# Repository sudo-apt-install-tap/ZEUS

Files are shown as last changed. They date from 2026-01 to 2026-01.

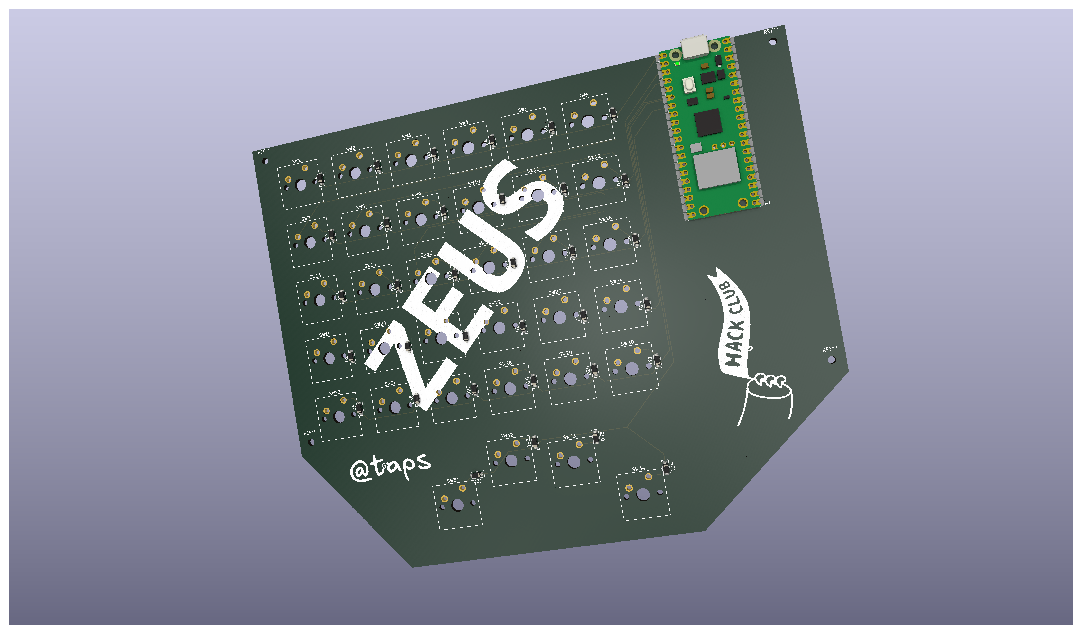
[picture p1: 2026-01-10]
Images/pcb.png

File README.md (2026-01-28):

# ZEUS: A One Handed Keeb Made For Speed
**No extra keys. Only essentials. Built for speed, precision, and one-handed precession.**

## Why ZEUS?
Zeus has a custom layout designed for speed and efficiency. This is based on a generic one handed gaming board.. yeah the kind you get on alibaba. BUT!! the diffrence is instead of keys numeric or function keys it has all alphabet keys. This make it perfect for speed typists.

## How Do I Flash ZEUS?
WHY WOULD YOU WANNA FLASH A GOD WHO HAS A HISTORY OF ADULTRY AND CREATING DEMIGODS. /j
But in all seriousness you just need to get the firmware and then just flash the code through any ide.

## RENDER
pcb


## PCB
PCB Layout
Matrix Routing
PCB Routing 1
PCB Routing 2

## Schematic
PCB Schematic

## BOM
### *not a bomb a BOM, Bill Of Materials*

| ID | Component | Qty | Designation | Supplier | Unit (INR) | Total (INR) |
|----|---|-----|---|---|---|---|
| 1 | Diode SMD 123 | 36 | 1N4148WT | [Robu](https://robu.in/product/tpmbr140sft1g-tech-public-sod-123-schottky-diodes-rohs/) | ₹2.49 | ₹89.64 |
| 2 | Switches (Pack of 10) | 4 | SW_Push | [StacksKB](https://stackskb.com/store/click-inc-hp-switch-pack-of-10-pre-order/) | ₹180.00 | ₹720.00 |
| 3 | Raspberry Pi Pico W | 1 | RaspberryPi_Pico_W | [Robu](https://robu.in/product/raspberry-pi-pico-w/) | ₹614.00 | ₹614.00 |
| 4 | Keycaps | 1 | — | [StacksKB](https://stackskb.com/store/veekos-gradient-keycaps-cherry-profile-135-keys/) | ₹1,299.00 | ₹1,299.00 |
| 5 | Hotswap Sockets | 34 | SW_Push | [StacksKB](https://stackskb.com/store/ttc-pokayoke-hotswap-sockets-v2-10000-cycles) | ₹10.00 | ₹340.00 |
| 6 | PCB Fabrication | 1 | — | [JLCPCB](https://cart.jlcpcb.com/shopcart/cart) | ₹2,294.11 | ₹2,294.11 |

---

### 💸 Cost Summary

- **Total (INR): ₹5,356.75**
- **Total (USD): ~$59.34**
- **Additional Cost [Case + Plate] (USD): $40**
- **Rounded:** **$100**

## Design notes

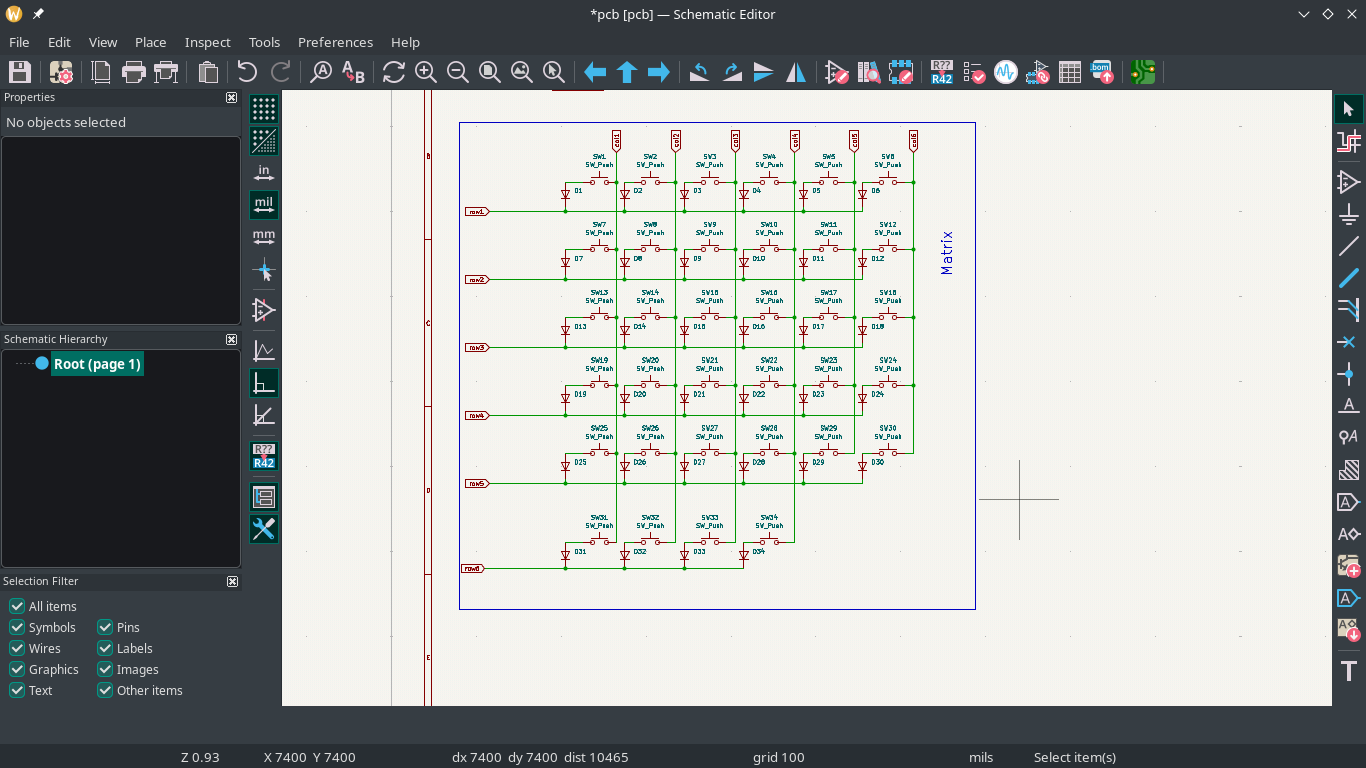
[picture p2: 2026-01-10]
Images/PCB Schematic.png

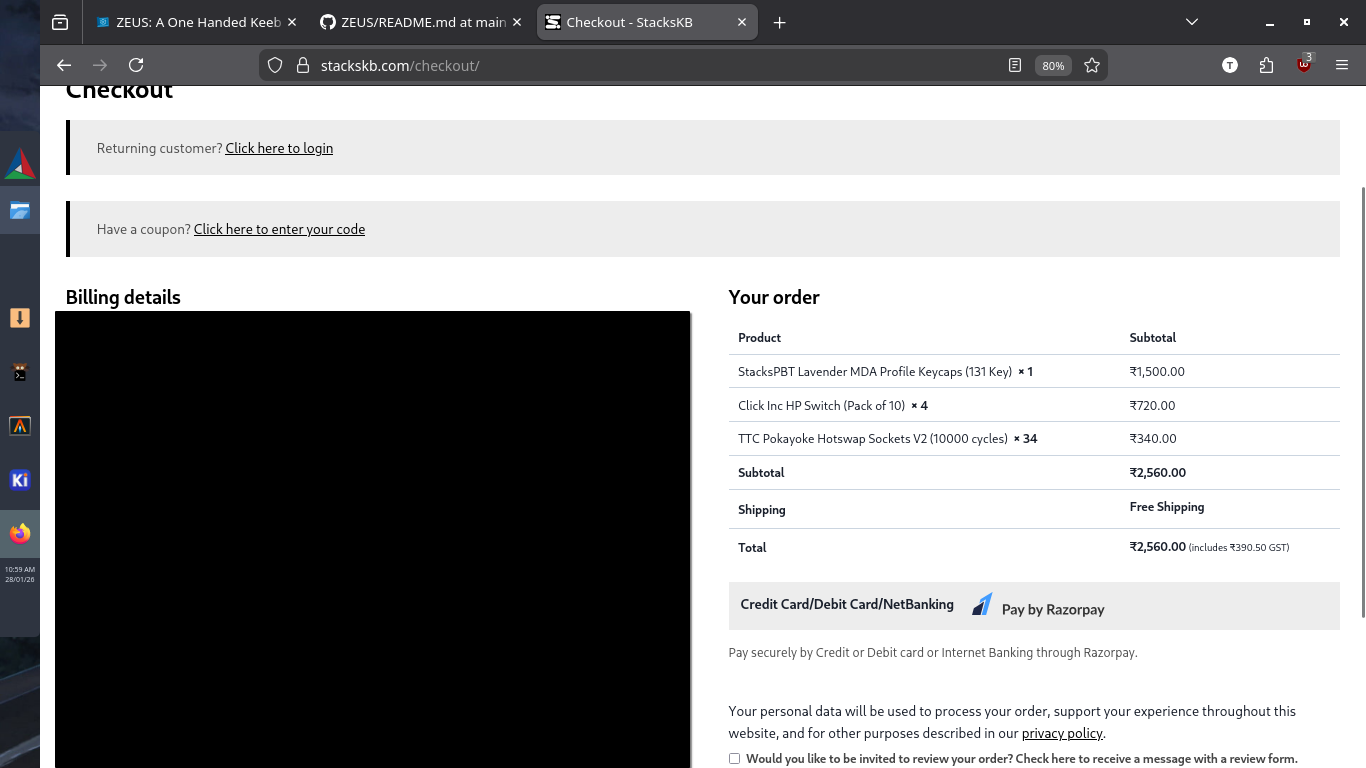
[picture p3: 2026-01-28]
Images/stackskb cart.png

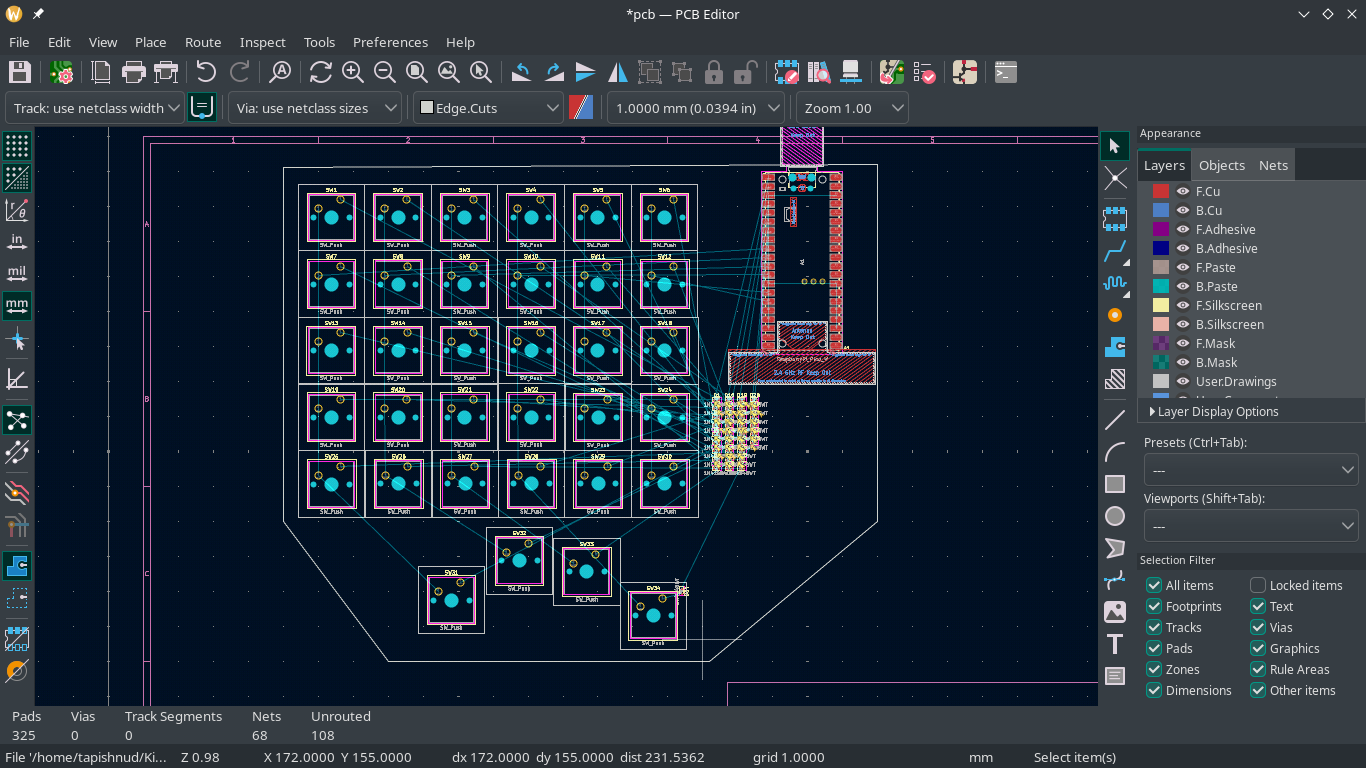
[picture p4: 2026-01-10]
Images/PCB Layout.png

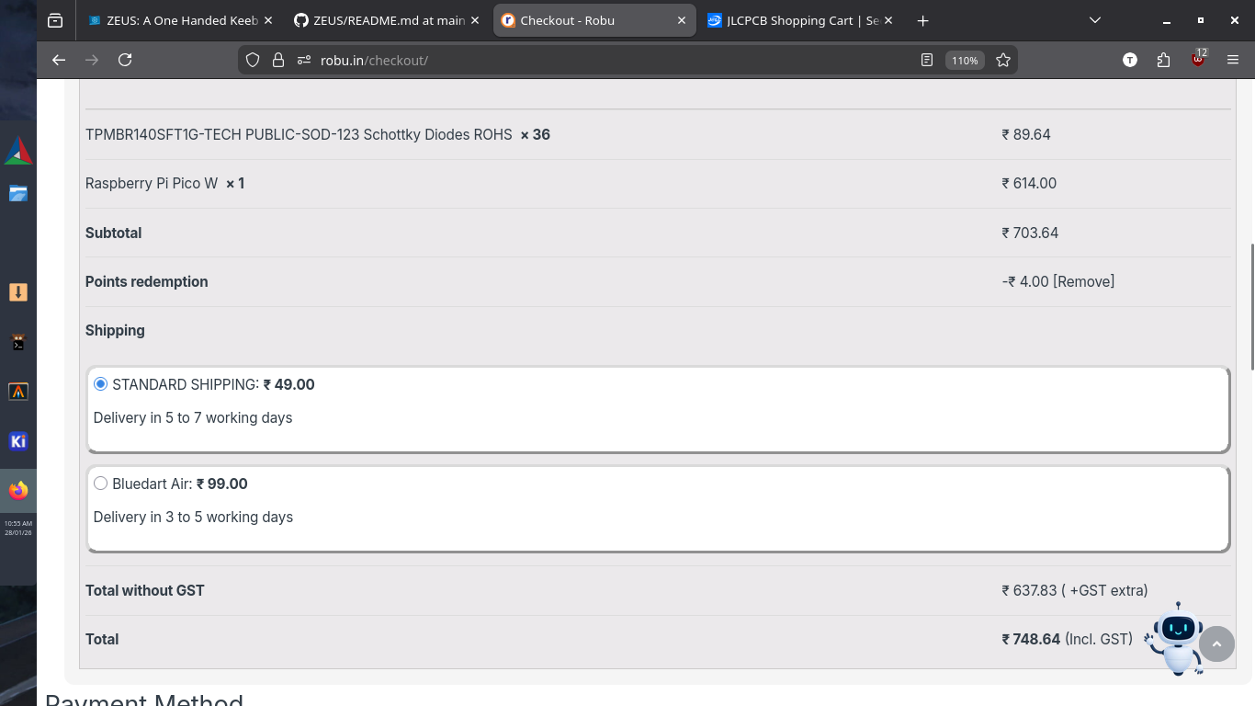
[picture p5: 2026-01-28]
Images/robu.in cart.png

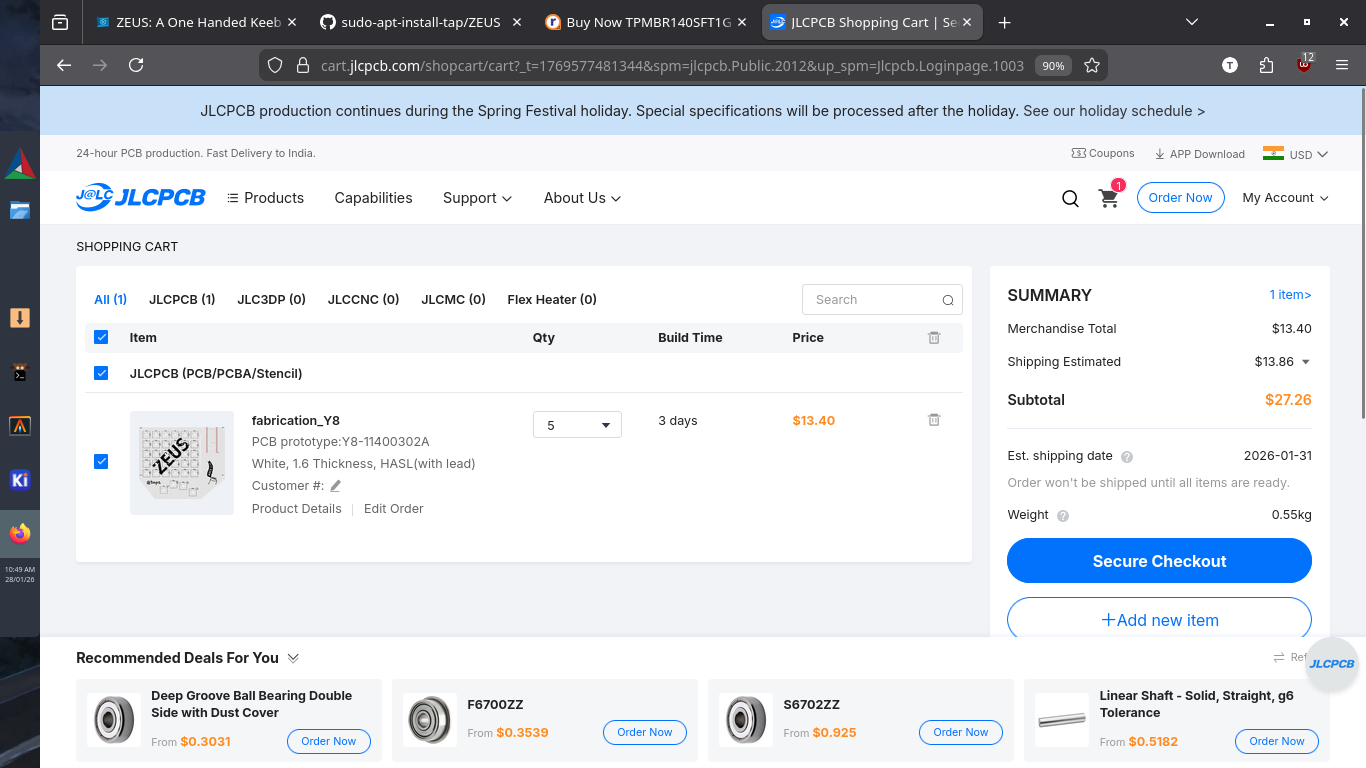
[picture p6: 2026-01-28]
Images/JLC PCB CART.png

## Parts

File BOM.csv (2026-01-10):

Id | Name | Quantity | Designation | Supplier and ref | Price Per Unit INR | Total INR
1 | Diode SMD 123 | 36 | 1N4148WT | https://robu.in/product/tpmbr140sft1g-tech-public-sod-123-schottky-diodes-rohs/ | ₹2.49 | ₹89.64
2 | Switches (Pack of 10) | 4 | SW_Push | https://stackskb.com/store/click-inc-hp-switch-pack-of-10-pre-order/ | ₹180.00 | ₹720.00
3 | RaspberryPi Pico W | 1 | RaspberryPi_Pico_W | https://robu.in/product/raspberry-pi-pico-w/ | ₹614.00 | ₹614.00
4 | Keycaps | 1 |  | https://stackskb.com/store/veekos-gradient-keycaps-cherry-profile-135-keys/ | ₹1,299.00 | ₹1,299.00
5 | Hotswap Sockets(Pack of 1) | 34 | SW_Push | https://stackskb.com/store/ttc-pokayoke-hotswap-sockets-v2-10000-cycles | ₹10.00 | ₹340.00
6 | PCB Fab | 1 |  | https://cart.jlcpcb.com/shopcart/cart | ₹2,294.11 | ₹2,294.11
 |  |  |  | TOTAL |  | ₹5,356.75
 |  |  |  | TOTAL USD |  | $59.34
 |  |  |  | Round off |  | $60

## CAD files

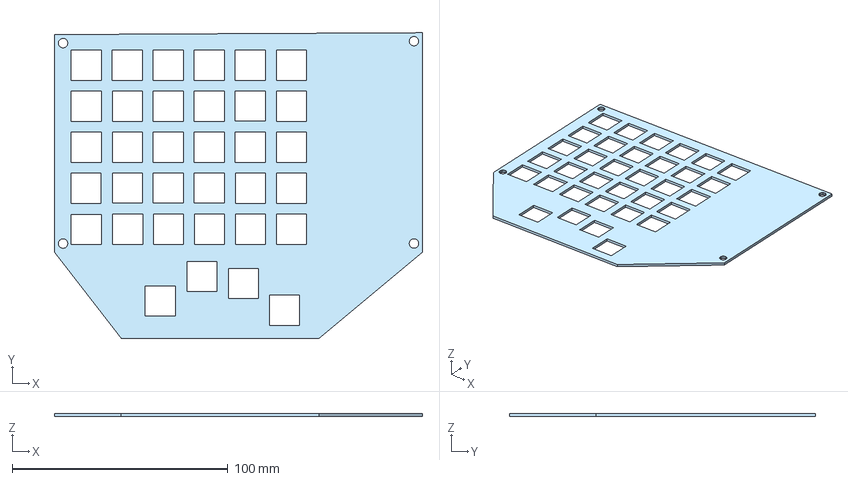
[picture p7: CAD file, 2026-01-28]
CAD/PLATE ZEUS.step
170.5 x 141.6 x 1.50 mm

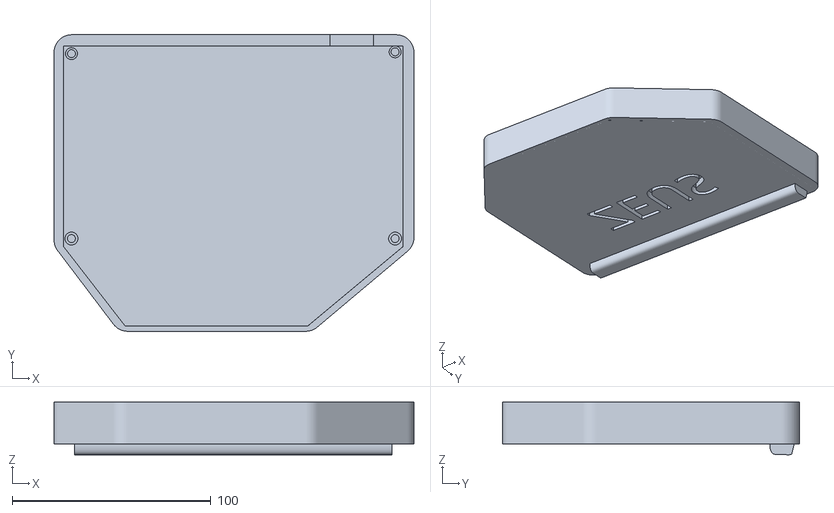
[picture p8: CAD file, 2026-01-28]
CAD/Production/ZEUS CASE.stl
181.2 x 149.3 x 26.5

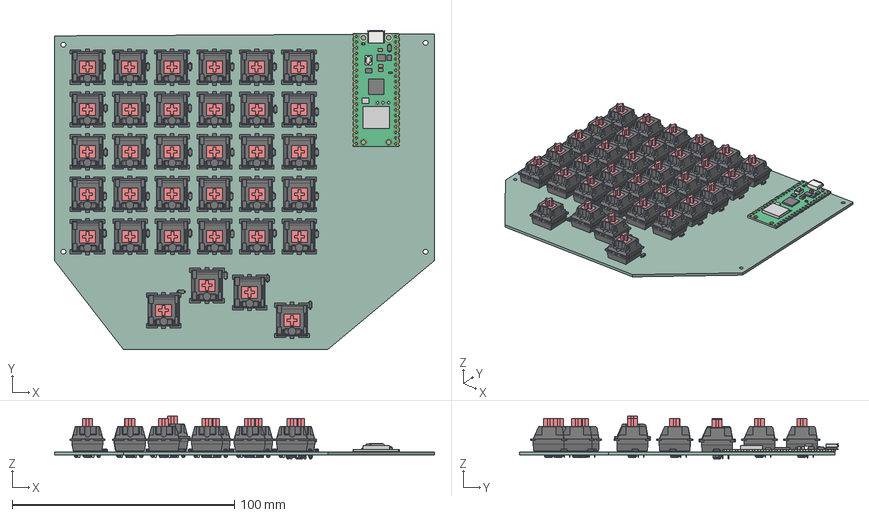
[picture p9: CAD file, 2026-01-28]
pcb/pcb.step
171.0 x 143.5 x 19.2 mm
D_SOD-123 x 34
RaspberryPi_Pico_W_Module_KiCad
pcb_PCB

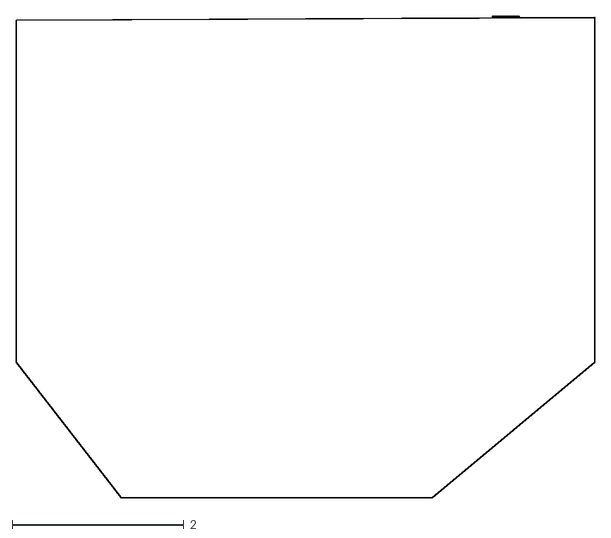
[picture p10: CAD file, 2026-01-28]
pcb/PLATE/pcb-Edge_Cuts.dxf
6.73 x 5.60

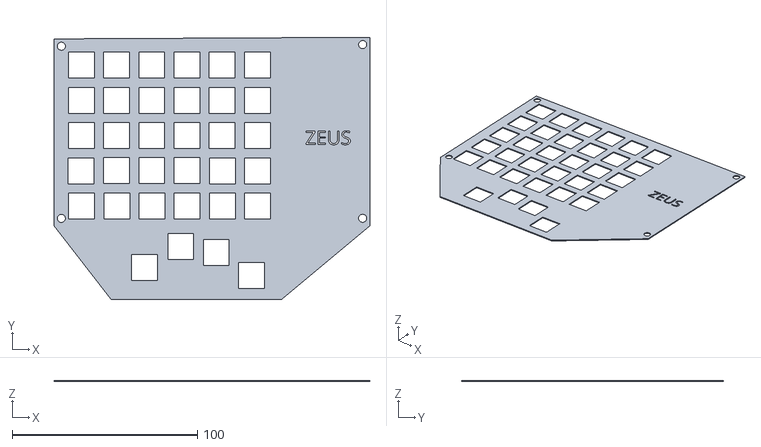
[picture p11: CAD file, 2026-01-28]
CAD/Production/Zeus Plate.stl
170.5 x 141.6 x 0.6

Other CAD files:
CAD/Case ZEUS.step

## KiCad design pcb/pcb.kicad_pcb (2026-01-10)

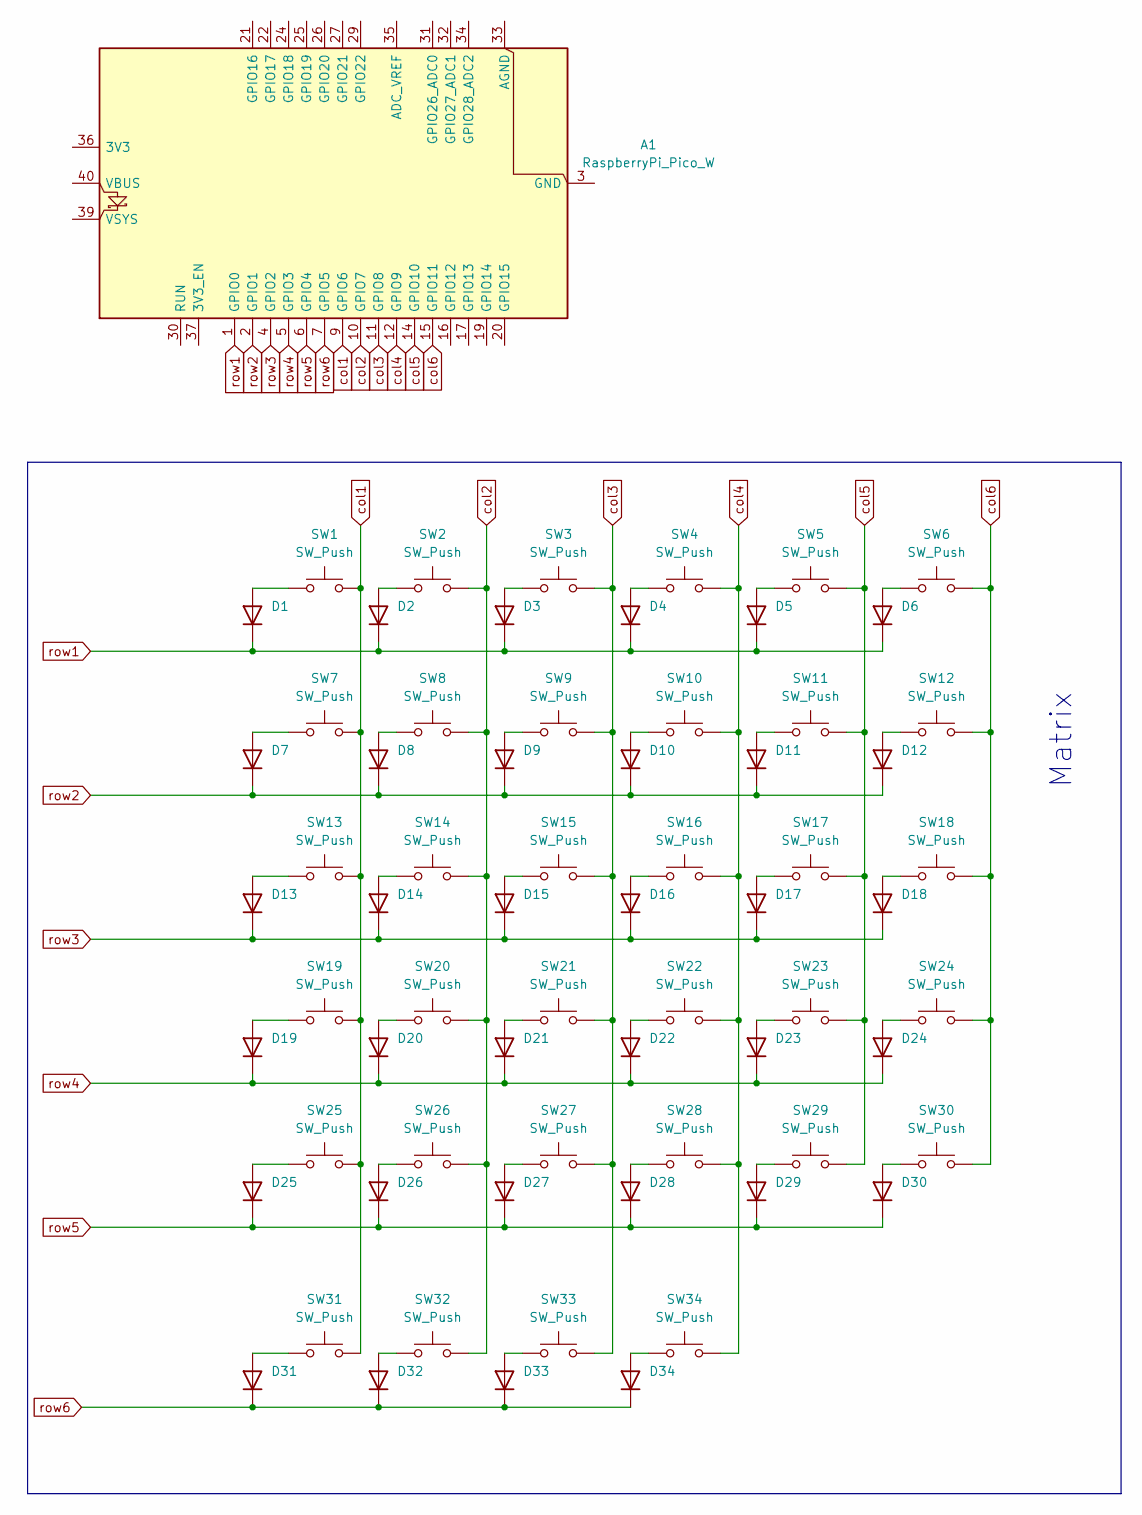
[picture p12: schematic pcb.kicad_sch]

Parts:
A1: RaspberryPi_Pico_W; RaspberryPi_Pico_W_SMD_HandSolder
D1, D2, D3, D4, D5, D6, D7, D8, D9, D10, D11, D12, D13, D14, D15, D16, D17, D18, D19, D20, D21, D22, D23, D24, D25, D26, D27, D28, D29, D30, D31, D32, D33, D34: 1N4148WT; D_SOD-523
SW1, SW2, SW3, SW4, SW5, SW6, SW7, SW8, SW9, SW10, SW11, SW12, SW13, SW14, SW15, SW16, SW17, SW18, SW19, SW20, SW21, SW22, SW23, SW24, SW25, SW26, SW27, SW28, SW29, SW30, SW31, SW32, SW33, SW34: SW_Push; SW_Cherry_MX_1.00u_PCB

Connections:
unnamed: A1.3 (GND), A1.8 (GND), A1.13 (GND), A1.18 (GND), A1.23 (GND), A1.28 (GND), A1.38 (GND)
unnamed: D1.2 (A), SW1.1
unnamed: D2.2 (A), SW2.1
unnamed: D3.2 (A), SW3.1
unnamed: D4.2 (A), SW4.1
unnamed: D5.2 (A), SW5.1
unnamed: D6.2 (A), SW6.1
unnamed: D7.2 (A), SW7.1
unnamed: D8.2 (A), SW8.1
unnamed: D9.2 (A), SW9.1
unnamed: D10.2 (A), SW10.1
unnamed: D11.2 (A), SW11.1
unnamed: D12.2 (A), SW12.1
unnamed: D13.2 (A), SW13.1
unnamed: D14.2 (A), SW14.1
unnamed: D15.2 (A), SW15.1
unnamed: D16.2 (A), SW16.1
unnamed: D17.2 (A), SW17.1
unnamed: D18.2 (A), SW18.1
unnamed: D19.2 (A), SW19.1
unnamed: D20.2 (A), SW20.1
unnamed: D21.2 (A), SW21.1
unnamed: D22.2 (A), SW22.1
unnamed: D23.2 (A), SW23.1
unnamed: D24.2 (A), SW24.1
unnamed: D25.2 (A), SW25.1
unnamed: D26.2 (A), SW26.1
unnamed: D27.2 (A), SW27.1
unnamed: D28.2 (A), SW28.1
unnamed: D29.2 (A), SW29.1
unnamed: D30.2 (A), SW30.1
unnamed: D31.2 (A), SW31.1
unnamed: D32.2 (A), SW32.1
unnamed: D33.2 (A), SW33.1
unnamed: D34.2 (A), SW34.1
col1: A1.9 (GPIO6), SW1.2, SW7.2, SW13.2, SW19.2, SW25.2, SW31.2
col2: A1.10 (GPIO7), SW2.2, SW8.2, SW14.2, SW20.2, SW26.2, SW32.2
col3: A1.11 (GPIO8), SW3.2, SW9.2, SW15.2, SW21.2, SW27.2, SW33.2
col4: A1.12 (GPIO9), SW4.2, SW10.2, SW16.2, SW22.2, SW28.2, SW34.2
col5: A1.14 (GPIO10), SW5.2, SW11.2, SW17.2, SW23.2, SW29.2
col6: A1.15 (GPIO11), SW6.2, SW12.2, SW18.2, SW24.2, SW30.2
row1: A1.1 (GPIO0), D1.1 (K), D2.1 (K), D3.1 (K), D4.1 (K), D5.1 (K), D6.1 (K)
row2: A1.2 (GPIO1), D7.1 (K), D8.1 (K), D9.1 (K), D10.1 (K), D11.1 (K), D12.1 (K)
row3: A1.4 (GPIO2), D13.1 (K), D14.1 (K), D15.1 (K), D16.1 (K), D17.1 (K), D18.1 (K)
row4: A1.5 (GPIO3), D19.1 (K), D20.1 (K), D21.1 (K), D22.1 (K), D23.1 (K), D24.1 (K)
row5: A1.6 (GPIO4), D25.1 (K), D26.1 (K), D27.1 (K), D28.1 (K), D29.1 (K), D30.1 (K)
row6: A1.7 (GPIO5), D31.1 (K), D32.1 (K), D33.1 (K), D34.1 (K)

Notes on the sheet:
Matrix

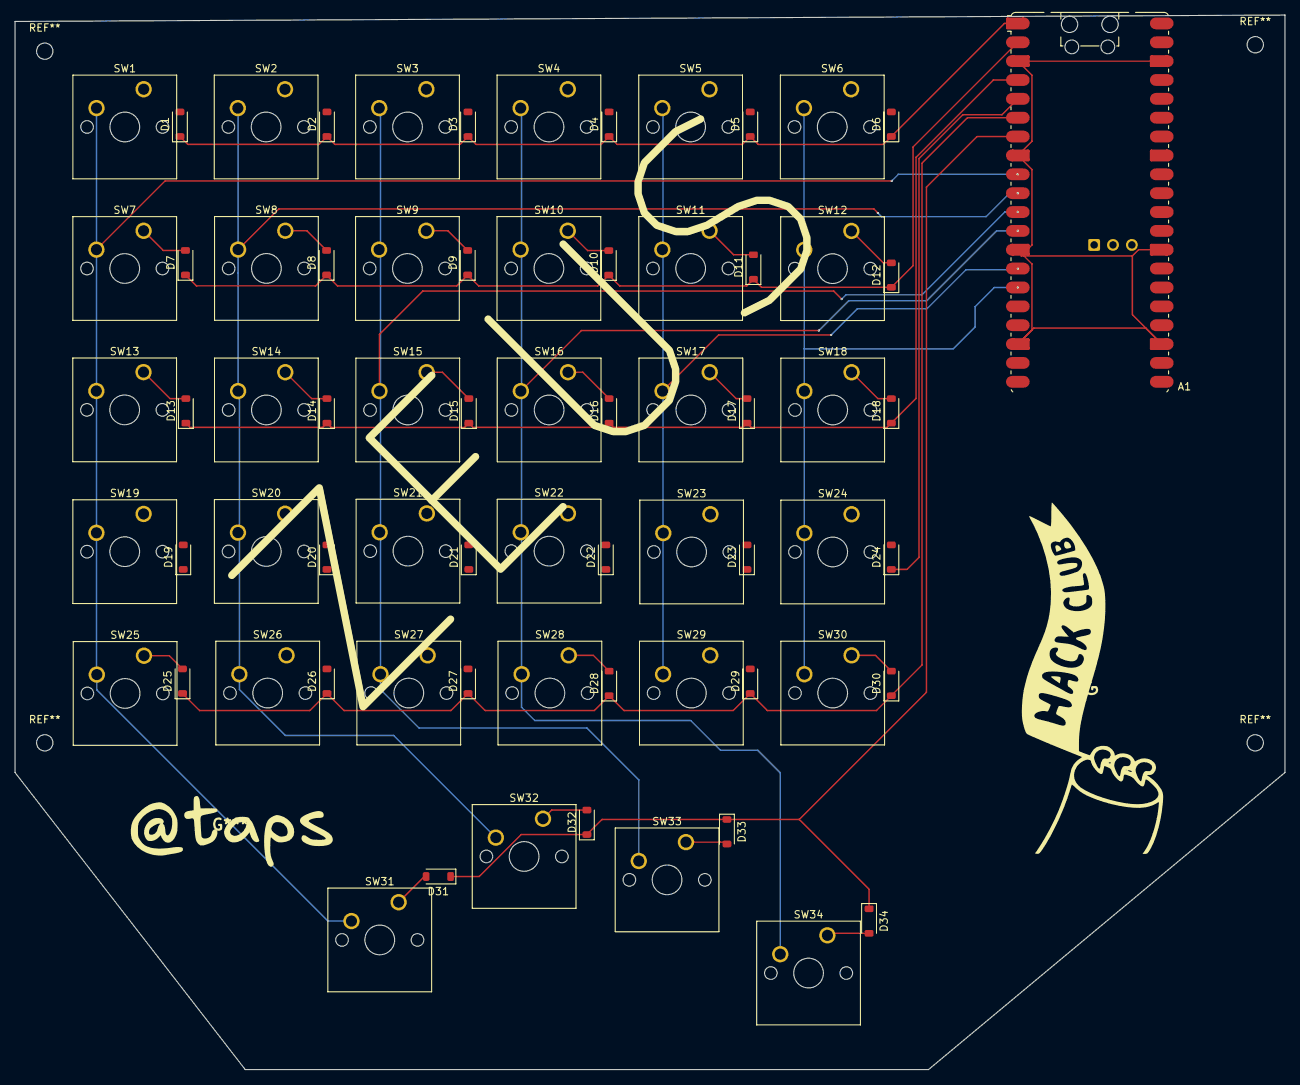
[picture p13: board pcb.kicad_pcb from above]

Board: 2 copper layers, 171.0 x 142.0 mm, 69 parts (0 on the bottom side), 47 nets.

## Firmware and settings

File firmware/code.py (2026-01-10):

import board
import usb_hid
from keypad import KeyMatrix
from adafruit_hid.keyboard import Keyboard
from adafruit_hid.keycode import Keycode

kbd = Keyboard(usb_hid.devices)

# ===== ROWS (R1 → R5) =====
R1 = board.GP0
R2 = board.GP1
R3 = board.GP2
R4 = board.GP3
R5 = board.GP4

ROWS = (R1, R2, R3, R4, R5)

# ===== COLUMNS (C1 → C6) =====
C1 = board.GP5
C2 = board.GP6
C3 = board.GP7
C4 = board.GP8
C5 = board.GP9
C6 = board.GP10

COLS = (C1, C2, C3, C4, C5, C6)

matrix = KeyMatrix(row_pins=ROWS, column_pins=COLS)

# ===== KEYMAP (R1C1 → R5C6) =====
keymap = [
    # R1
    Keycode.Q, Keycode.W, Keycode.E, Keycode.R, Keycode.T, Keycode.Y,

    # R2
    Keycode.A, Keycode.S, Keycode.D, Keycode.F, Keycode.G, Keycode.H,

    # R3
    Keycode.Z, Keycode.X, Keycode.C, Keycode.V, Keycode.B, Keycode.N,

    # R4
    Keycode.U, Keycode.I, Keycode.O, Keycode.P, Keycode.L, Keycode.SEMICOLON,

    # R5
    Keycode.LEFT_CONTROL,
    Keycode.SPACE,
    Keycode.ENTER,
    Keycode.LEFT_SHIFT,
    None,
    None,
]

# ===== MAIN LOOP =====
while True:
    event = matrix.events.get()
    if event:
        keycode = keymap[event.key_number]
        if keycode is None:
            continue

        if event.pressed:
            kbd.press(keycode)
        else:
            kbd.release(keycode)

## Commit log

2026-01-10 Add ZEUS keyboard details to README
    Added detailed information about ZEUS keyboard including layout, flashing instructions, images, and BOM.
2026-01-10 Update BOM section formatting in README.md
2026-01-10 Modify BOM section header formatting
    Updated BOM section header to include HTML line break.
2026-01-28 Update README with BOM section and images
2026-01-28 Enhance README with details about ZEUS keyboard
    Updated the README with additional information about ZEUS, including its layout, flashing instructions, and PCB images.
2026-01-28 Updated Images with cart
    [Case ZEUS.step, PLATE ZEUS.step, ZEUS CASE.stl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]
